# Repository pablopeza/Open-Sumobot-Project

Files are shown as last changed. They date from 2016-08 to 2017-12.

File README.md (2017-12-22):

# Open-Sumobot-Project
## Post on my blog
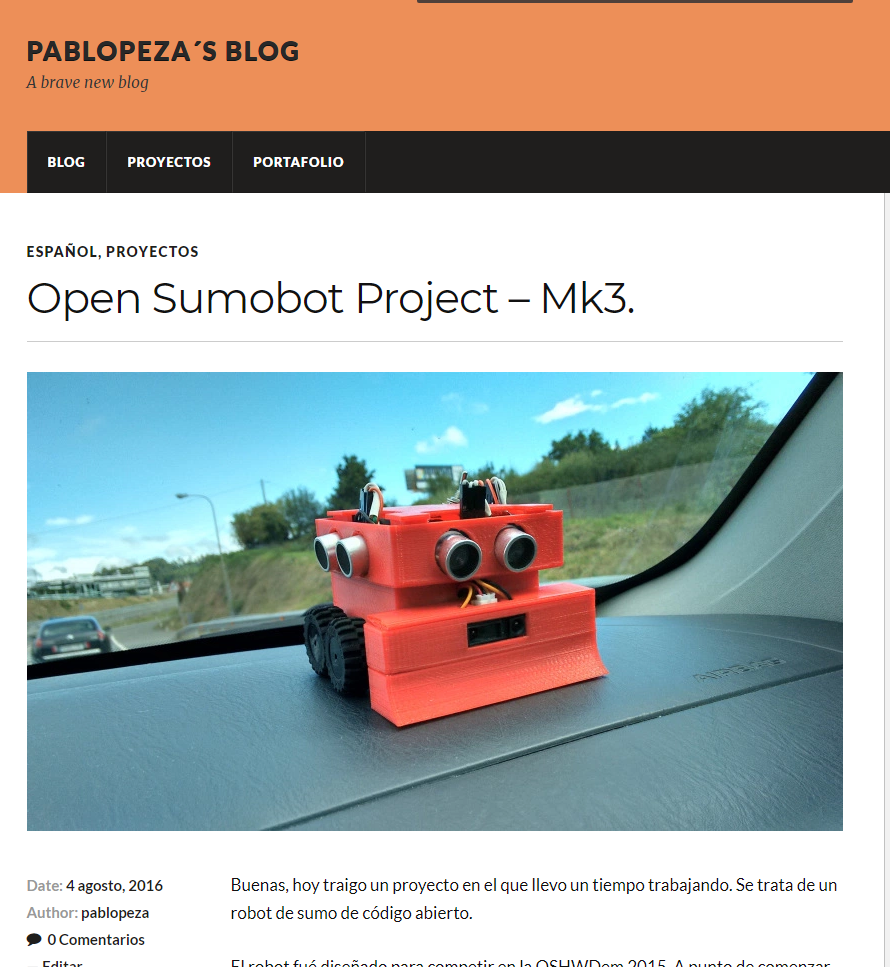
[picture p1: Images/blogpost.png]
blog

https://pablopezasblog.wordpress.com/2016/08/04/open-sumobot-project-mk3/
## Electronics
* 1x Arduino nano V3
* 3x Hsr04 ultrasonic distance sensors
* 1x l991s Motor driver
* 1x Power switch
* 2x Tcrt5000 line sensors
* (Optional) 1 IR SHARP distance sensor
  ## Schematic

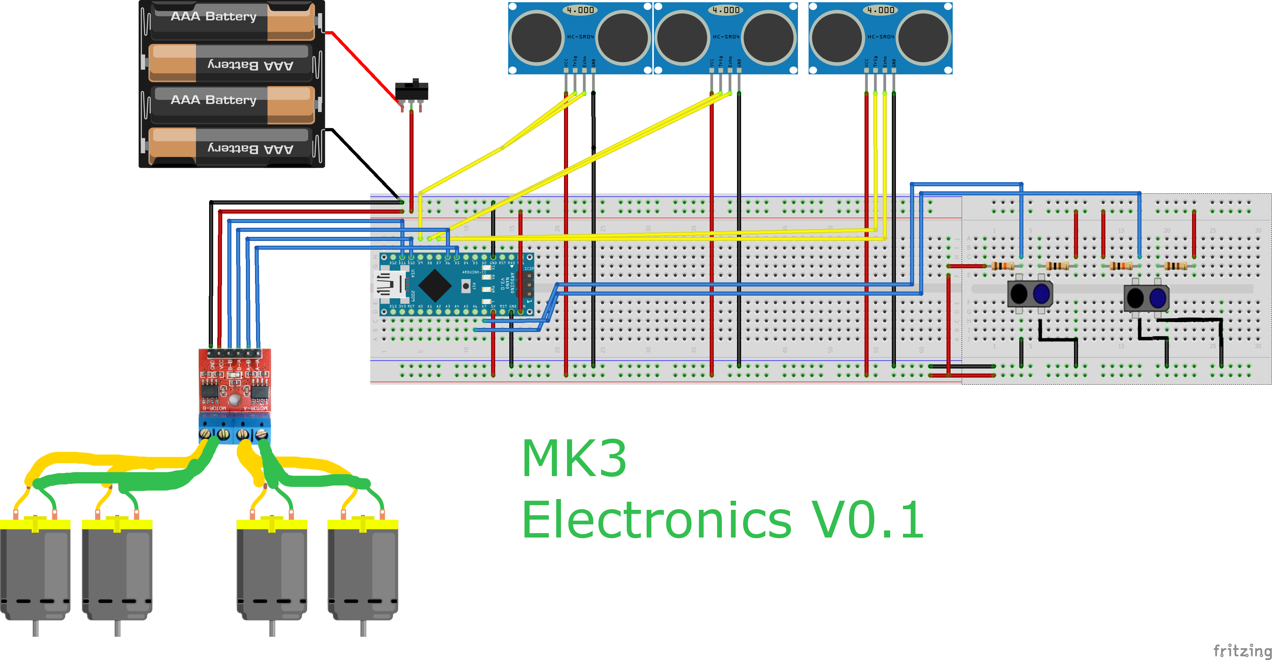
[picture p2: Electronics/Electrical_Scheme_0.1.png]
electronics
  

## Motion
* 4x N20 6V 200rpm motors
* 4x Lego rubber wheels
* 4x Wheel.stl

  ## 3D Printable parts
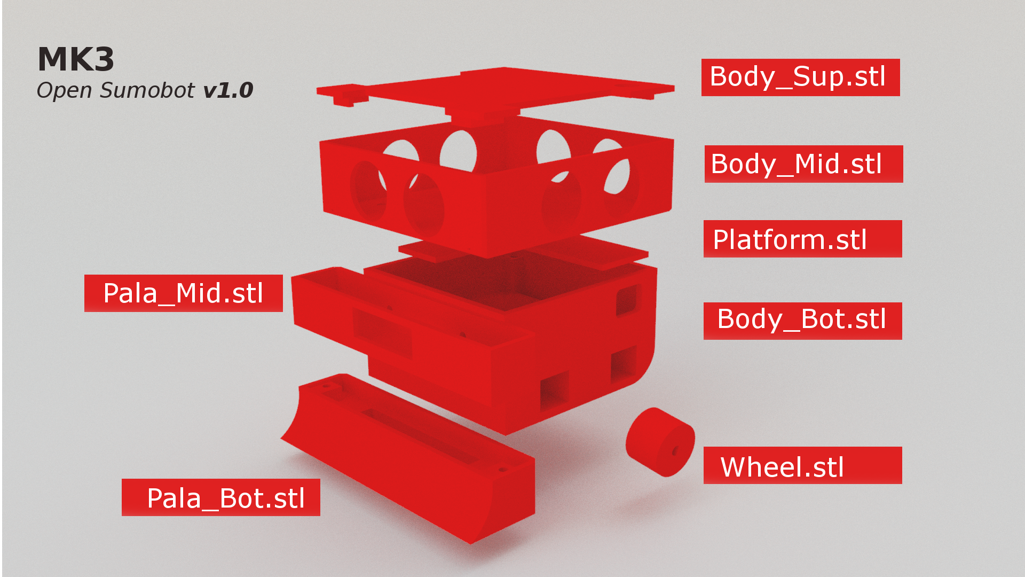
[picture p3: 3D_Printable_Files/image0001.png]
hw


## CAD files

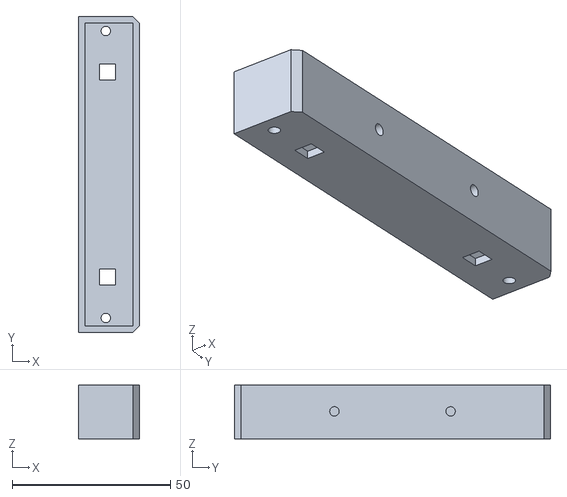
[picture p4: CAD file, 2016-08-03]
3D_Printable_Files/Pala_Mid.stl
19.2 x 100.0 x 17.0

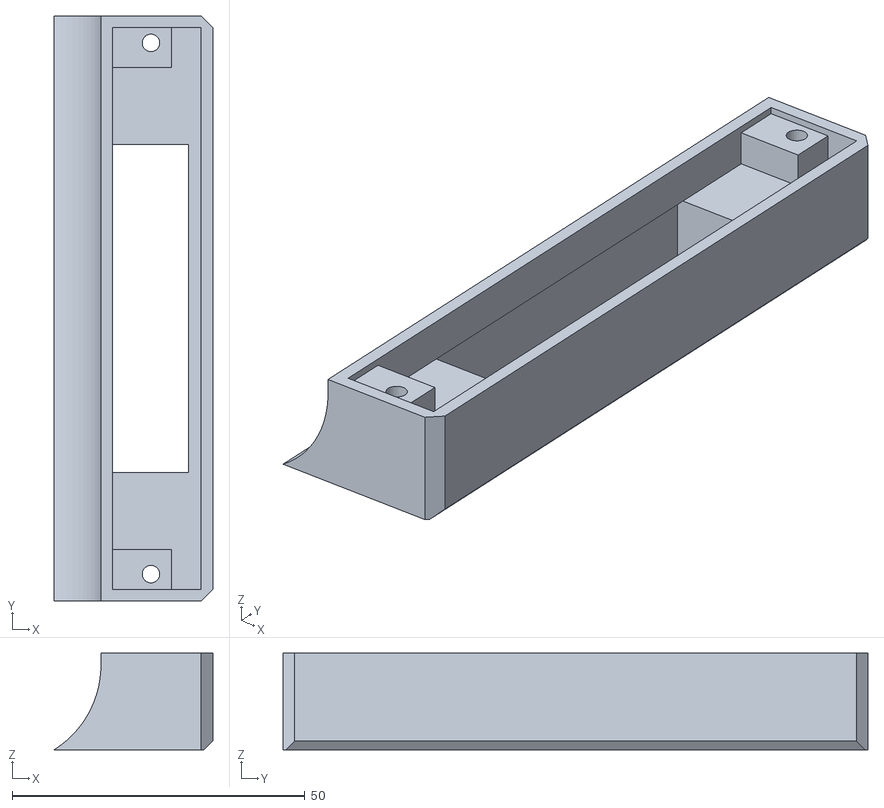
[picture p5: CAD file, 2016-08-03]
3D_Printable_Files/Pala_Bot.stl
27.1 x 100.0 x 16.5

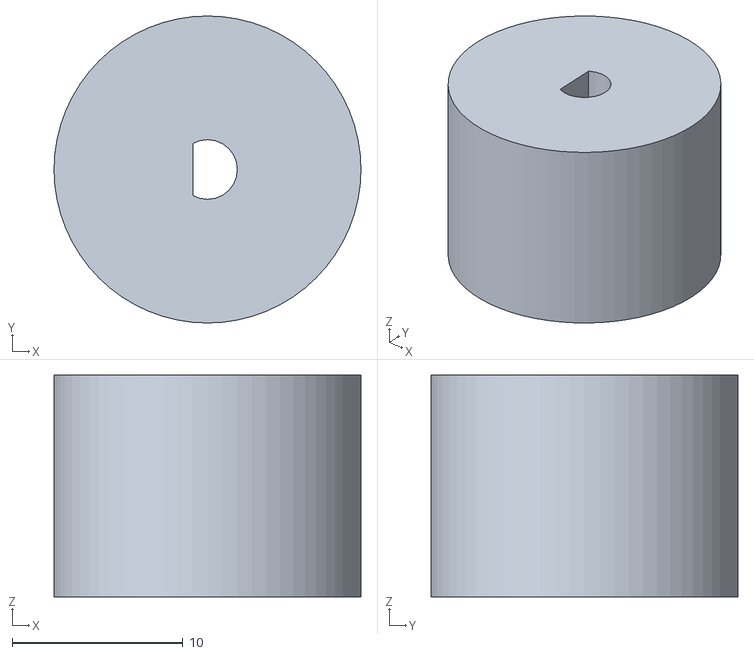
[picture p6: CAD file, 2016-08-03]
3D_Printable_Files/Wheel.stl
18.0 x 18.0 x 13.0

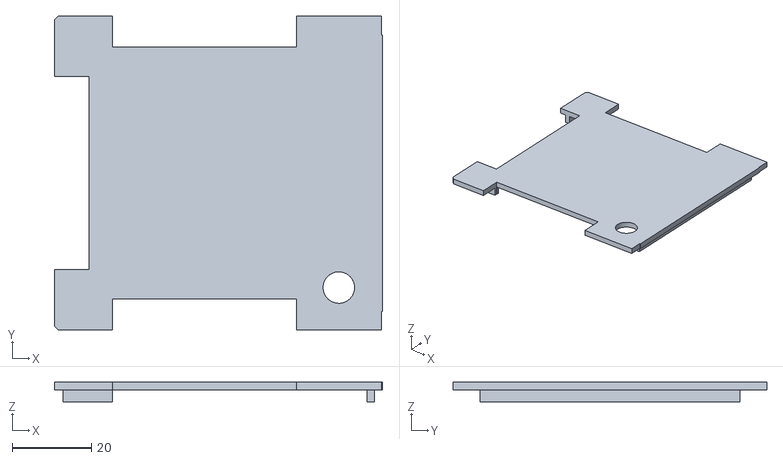
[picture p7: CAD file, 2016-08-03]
3D_Printable_Files/Body_Sup.stl
83.1 x 79.4 x 5.00

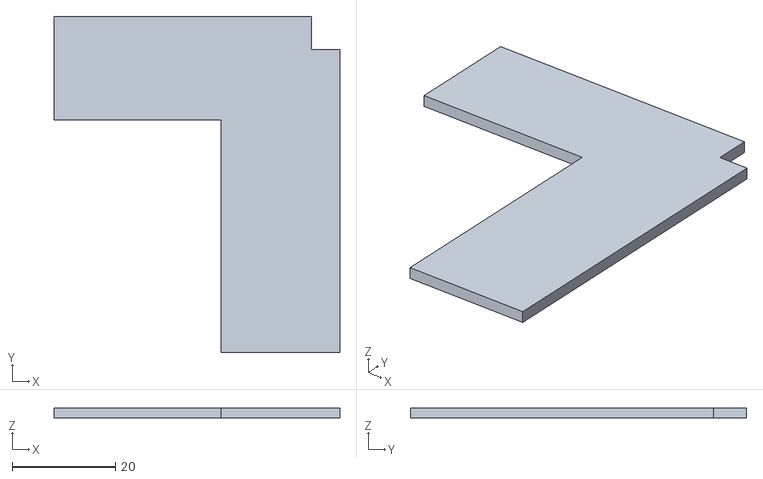
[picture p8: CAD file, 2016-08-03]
3D_Printable_Files/Platform.stl
55.3 x 65.0 x 2.00

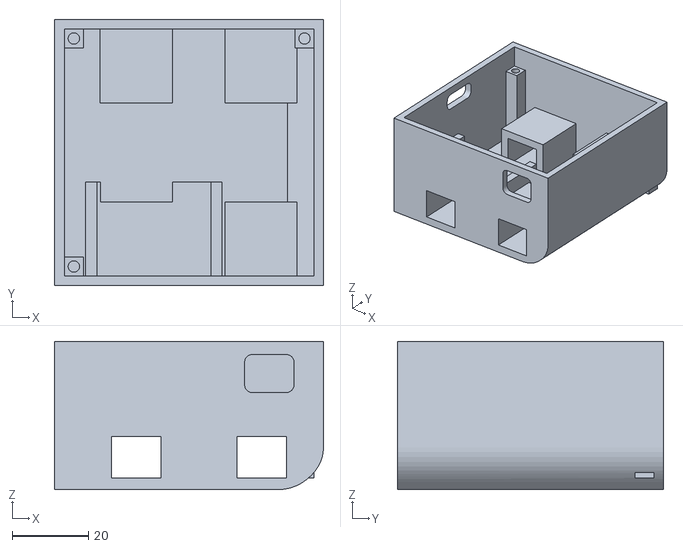
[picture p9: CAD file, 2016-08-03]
3D_Printable_Files/Body_Bot.stl
70.8 x 70.0 x 39.0

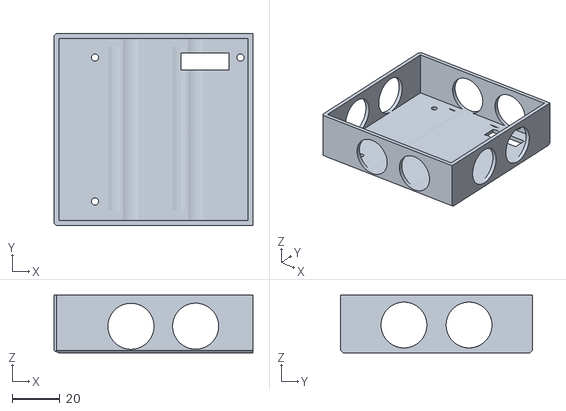
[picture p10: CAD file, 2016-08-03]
3D_Printable_Files/Body_Mid.stl
83.0 x 80.0 x 24.0

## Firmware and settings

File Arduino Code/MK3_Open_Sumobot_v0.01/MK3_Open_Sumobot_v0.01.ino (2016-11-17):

/*
 * MK3 Open Sumobot Firmware V_0.01
 * CC license
 * @pablopeza
 * 
 * Contains NewPing.h library created by Tim Eckel - teckel@leethost.com
 * Copyright 2012 License: GNU GPL v3 http://www.gnu.org/licenses/gpl-3.0.html
 */
 
#include <NewPing.h>
#define PING 55 //Max distance reading
  NewPing izq(9, 9, PING);  //Only 1 wire for comunication with this sensor    
  NewPing dch(8, 8, PING);  //Only 1 wire for comunication with this sensor
  NewPing fnt(7, 7, PING);  //Only 1 wire for comunication with this sensor

#define DISTANCIA 30
#define DISTANCIA_IR 40
#define NUMERONEGRO 300

#define HG7881_IA2 6  // D10 --> Motor B Input A --> MOTOR B +
#define HG7881_IB2 11 // D11 --> Motor B Input B --> MOTOR B -
#define HG7881_IA1 5  // D5  --> Motor A Input A --> MOTOR A +
#define HG7881_IB1 10 // D6  --> Motor A Input B --> MOTOR A -

#define MOTOR_B_PWM HG7881_IA2 // Motor B PWM Speed
#define MOTOR_B_DIR HG7881_IB2 // Motor B Direction
#define MOTOR_A_PWM HG7881_IA1 // Motor A PWM Speed
#define MOTOR_A_DIR HG7881_IB1 // Motor A Direction

int line_sensor_right;

int cont = 0;
int redpin=A3;

int line_left, line_right;

int front_distance = 0;
int left_distance = 0;
int right_distance = 0;

boolean turn_direction = true;        //The last movement was a turn, this is for repair the sensors orientation bug 
boolean front_detection = false;      //True when detects an enemy

unsigned long time;

 /*                                          [1]                          
  *                                        __._.__
  *  left_distance      left              |       |
  *  front_distance     center       [0] <|       |> [2]
  *  right_distance     right             |       |
  *                                         -------
  *  Movements available:  
  *     - sumo_forward(speed)
  *     - sumo_left(speed)
  *     - sumo_right(speed)
  *     - sumo_backward(speed)
  *     - sumo_stop(speed)
   */

  
void setup() 
  {
  pinMode( MOTOR_B_DIR, OUTPUT );
  pinMode( MOTOR_B_PWM, OUTPUT );
  digitalWrite( MOTOR_B_DIR, LOW );
  digitalWrite( MOTOR_B_PWM, LOW );

  pinMode( MOTOR_A_DIR, OUTPUT );
  pinMode( MOTOR_A_PWM, OUTPUT );
  digitalWrite( MOTOR_A_DIR, LOW );
  digitalWrite( MOTOR_A_PWM, LOW );

  Serial.begin(9600);
 
  delay(1);
  }

void loop() 
  {
  time = millis();  
  left_distance = ping_sensor_left_raw();
  front_distance = ping_sensor_center_raw();
  right_distance = ping_sensor_right_raw();
  
  line_right = line_sensor_right_raw();
  line_left = line_sensor_left_raw();

  Serial.print(" L");
  print_data(left_distance);
  Serial.print(" C");
  print_data(front_distance);
  Serial.print(" R");
  print_data(right_distance);
  Serial.print(" LI ");
  print_data(line_left);
  Serial.print(" LD ");
  print_data(line_right);
  Serial.print(" time ");
  Serial.print(time);
  
  if(front_distance <= 50)
    {
    sumo_forward(250);
    delay(30);
    }else
      {
       if((left_distance < front_distance) && (left_distance < right_distance)) //add states
         {
         sumo_left(250);
         }
         
       if((right_distance < front_distance) && (right_distance < front_distance))
         {
         sumo_right(250);
         }
      }     
  if((line_right < 200)||(line_left < 200))
      {
      sumo_backward(200);
      delay(100);
      sumo_left(250);
      delay(100);
      }       
  Serial.println("");    
  }
  

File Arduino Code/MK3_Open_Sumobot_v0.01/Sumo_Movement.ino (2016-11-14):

void sumo_forward(int motor_speed)
  {
  digitalWrite( MOTOR_B_DIR, HIGH );              // Direction : Forward
  analogWrite( MOTOR_B_PWM, 255 - motor_speed );  // Motor_speed : PWM 
  digitalWrite( MOTOR_A_DIR, HIGH );              // Direction : Forward
  analogWrite( MOTOR_A_PWM, 255 - motor_speed );  // Motor_speed : PWM 
  }

void sumo_right(int motor_speed)
  {
  digitalWrite( MOTOR_B_DIR, HIGH );              // Direction : Forward
  analogWrite( MOTOR_B_PWM, 255 - motor_speed );  // Motor_speed : PWM
  digitalWrite( MOTOR_A_DIR, LOW );               // Direction : Backward
  analogWrite( MOTOR_A_PWM, motor_speed );        // Motor_speed : PWM
  }

void sumo_left(int motor_speed)
  {
  digitalWrite( MOTOR_B_DIR, LOW );               // Direction : Backward
  analogWrite( MOTOR_B_PWM,  motor_speed );       // Motor_speed : PWM
  digitalWrite( MOTOR_A_DIR, HIGH );              // Direction : Forward
  analogWrite( MOTOR_A_PWM,255 - motor_speed );   // Motor_speed : PWM
  }

void sumo_left2(int motor_speed)
  {
  digitalWrite( MOTOR_B_DIR, LOW );               // Direction : Backward
  analogWrite( MOTOR_B_PWM,  motor_speed );       // Motor_speed : PWM
  
  digitalWrite( MOTOR_A_DIR, HIGH );              // Direction : Forward
  analogWrite( MOTOR_A_PWM,255 );                 // Motor_speed : PWM
  }

void sumo_backward(int motor_speed)
  {
  digitalWrite( MOTOR_B_DIR, LOW );               // Direction : Backward
  analogWrite( MOTOR_B_PWM, motor_speed );        // Motor_speed : PWM
  digitalWrite( MOTOR_A_DIR, LOW );               // Direction : Backward
  analogWrite( MOTOR_A_PWM, motor_speed );        // Motor_speed : PWM
  }

void sumo_stop()
  {
  digitalWrite( MOTOR_B_DIR, LOW );
  digitalWrite( MOTOR_B_PWM, LOW );
  digitalWrite( MOTOR_A_DIR, LOW );
  digitalWrite( MOTOR_A_PWM, LOW );
  }

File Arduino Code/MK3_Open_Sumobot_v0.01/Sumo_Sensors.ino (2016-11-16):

//This code colects the data of the sensors of the sumo and save them into variables

int ping_sensor_left_raw()   //This function takes the value of the distance from the library of the ultrasonic sensors
  {
  int cmi = izq.ping_cm();   //Left Ping Sensor
  if (cmi <= 0)
    {
    cmi = PING;
    }
  return cmi;
  }

int ping_sensor_right_raw()  //Right Ping Sensor
  {
  int cmd = dch.ping_cm(); 
  if (cmd <= 0)
    {
    cmd = PING;
    }
  return cmd;
  }

int ping_sensor_center_raw()  //Center Ping Sensor
  {
  int cmc = fnt.ping_cm(); 
  if (cmc == 0)
    {
    cmc= PING;
    }
  return cmc;  
  }

int line_sensor_right_raw()   //Line Sensor Right
  {
  int sensorValue = analogRead(A7);
  return sensorValue;
  }

int line_sensor_left_raw()    //Line Sensor Left
  {
  int sensorValue = analogRead(A6); 
  return sensorValue; 
  }

int ir() //IR Sensor Front
  {
  int i,val;
  i=analogRead(redpin);
  val=(6762/(i-9))-4;
  if(val > DISTANCIA_IR)
    {
    val = DISTANCIA_IR;
    }
  return val;
  }

void print_data(int data)   //Function used to print properly the sensor data.
  {                         //If the number is not big enought, the function adds blank spaces.
  Serial.print(" ");        // bad 1 20 300     /without function
  if(data < 1000)           // bad 100 20 1     /without function
    {                       // well   1  20 300 /with function
      if(data < 100)        // well 300  20   1 /with function
        {
        Serial.print(" ");
        if(data < 10)
          {
          Serial.print(" ");
          }
        }
    }
  Serial.print(data);  
  }

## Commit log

2016-08-03 Stl Añadido
    [Body_Bot.stl, Body_Mid.stl, Body_Sup.stl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]
2016-08-03 Eliminada pieza
    [Pala_Sup.stl]
